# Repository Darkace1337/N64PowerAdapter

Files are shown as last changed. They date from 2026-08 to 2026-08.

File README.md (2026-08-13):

# N64PowerAdapter

A modern, universal replacement power supply for the Nintendo 64 using readily available, high-quality power modules.

This project includes the PCB design, schematic, and 3D-printable enclosure required to build a replacement for the original Nintendo 64 power supply. The supply accepts universal AC mains through an IEC C8 connector and provides the 12 V and 3.3 V rails required by the N64 through the original 6-pin power connector.

The design uses TRACO Power modules for the AC/DC and DC/DC conversion, keeping the power circuitry simple while providing an isolated and compact replacement for aging original power supplies.

## Requirements

**A sacrificial Nintendo 64 power adapter (official or third-party) is required for the original 6-pin console connector.**

The connector must be removed from the donor power supply and installed onto the replacement PCB.

## Bill of Materials

| Reference | Qty | Manufacturer | Part Number | Description |
|:---|---:|:---|:---|:---|
| PS1 | 1 | TRACO Power | TEL 10-2410WI | 10 W isolated DC/DC converter, 9–36 V input, 3.3 V / 2.7 A output |
| PS2 | 1 | TRACO Power | TMPW 25-112 | 25 W AC/DC converter, 12 V / 2.083 A output |
| C1 | 1 | KYOCERA AVX | TAJD476K025SNJ | 47 µF, 25 V, 10% tantalum capacitor |
| C2, C4 | 2 | Vishay | 05007-BR104AKU-J | 0.1 µF, 25 V, 10% MLCC |
| C5 | 1 | Vishay | 592D477X96R3C2T20H | 470 µF, 6.3 V, 10% tantalum capacitor |
| F1 | 1 | Eaton | C310T-SC-2-5-R-TR1 | 2.5 A, 250 V ceramic cartridge fuse |
| J1 | 1 | — | Amazon | C8 Panel Mount Plug, flange mount type |
| J3 | 1 | Nintendo / Donor PSU | — | Original N64 6-pin power connector |
| Screws-A | 3 | - | Amazon | M3 x 5 mm Button-head machine screws
| Screws-B | 4 | - | Amazon | M3 x 6 mm Countersunk self tapping screws
| Thread Inserts| 2 | - | Amazon | M3 x 4 mm Heat-set insets

## Project Files

* Schematic and PCB design
* Gerber/manufacturing files
* 3D-printable enclosure
* Reference photos of the assembled prototype

## Prototype / Revision Note

**The photos shown below are of an earlier prototype revision.**

The PCB used in the photographed prototype required a small section of the board to be manually cut for proper mechanical fitment. The PCB layout has since been revised to correct this interference.

The current revision is intended to fit without this modification, but has not yet been physically verified in the same configuration shown in the photos.

## Photos

<p align="center">
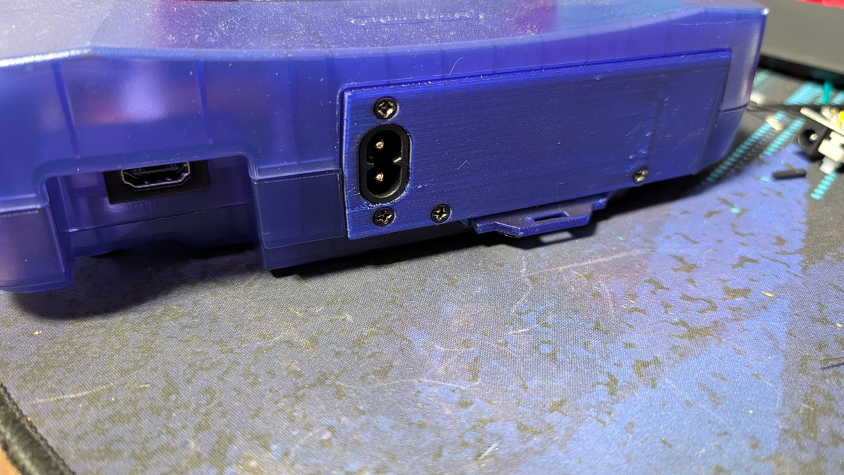
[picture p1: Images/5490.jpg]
N64 Power Adapter installed
  
</p>

<p align="center">
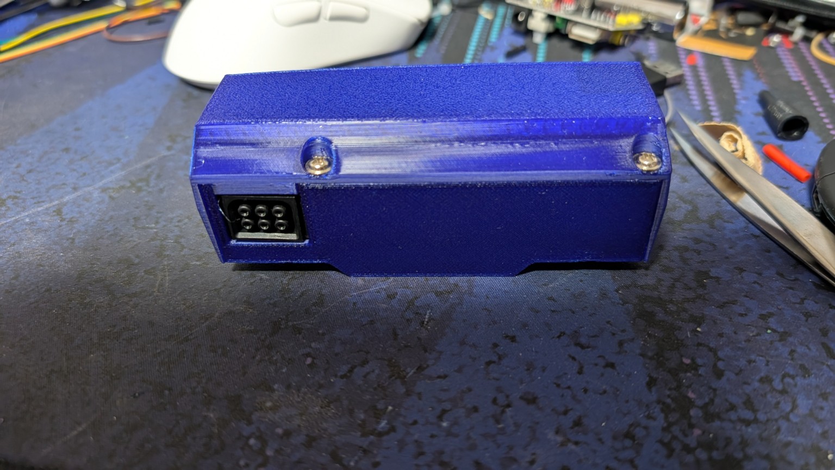
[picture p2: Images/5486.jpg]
  
</p>

<p align="center">
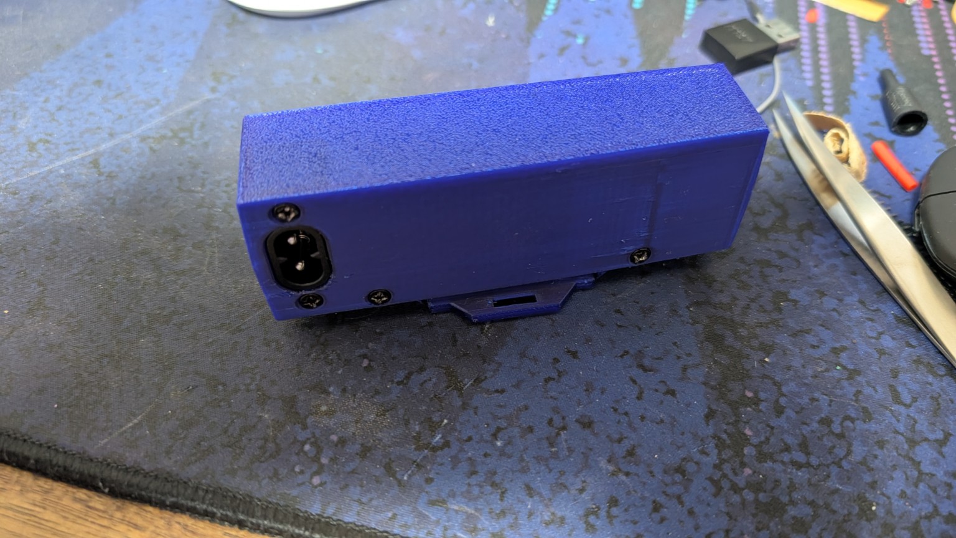
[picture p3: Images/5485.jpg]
  
</p>

<p align="center">
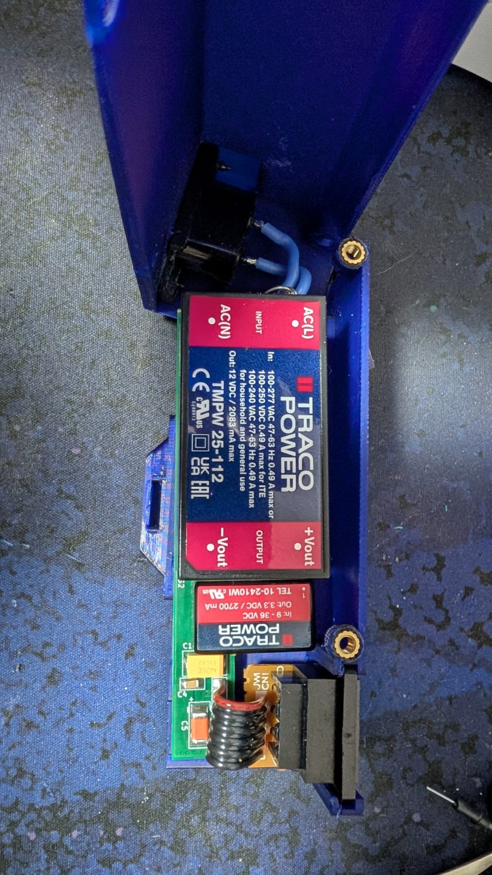
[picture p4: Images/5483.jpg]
N64 Power Adapter internal assembly
  
</p>

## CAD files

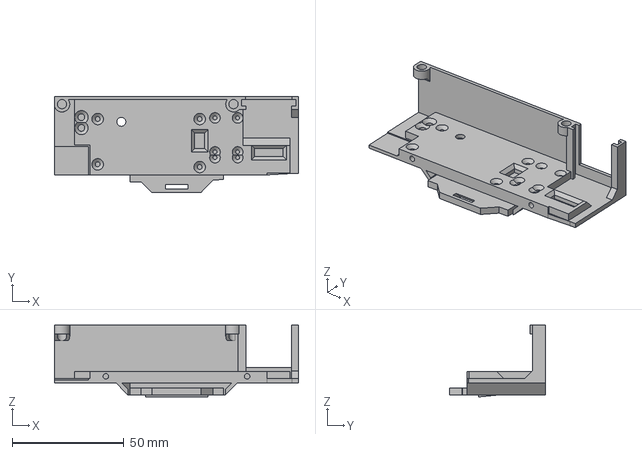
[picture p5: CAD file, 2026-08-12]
3d Print Shell/N64Power - Lower Shell.step
109.3 x 43.2 x 32.2 mm

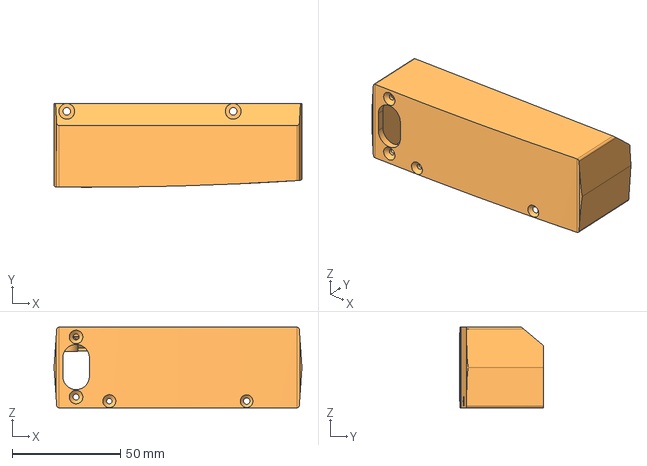
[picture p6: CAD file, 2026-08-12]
3d Print Shell/N64Power - Upper Shell.step
114.5 x 38.6 x 37.2 mm

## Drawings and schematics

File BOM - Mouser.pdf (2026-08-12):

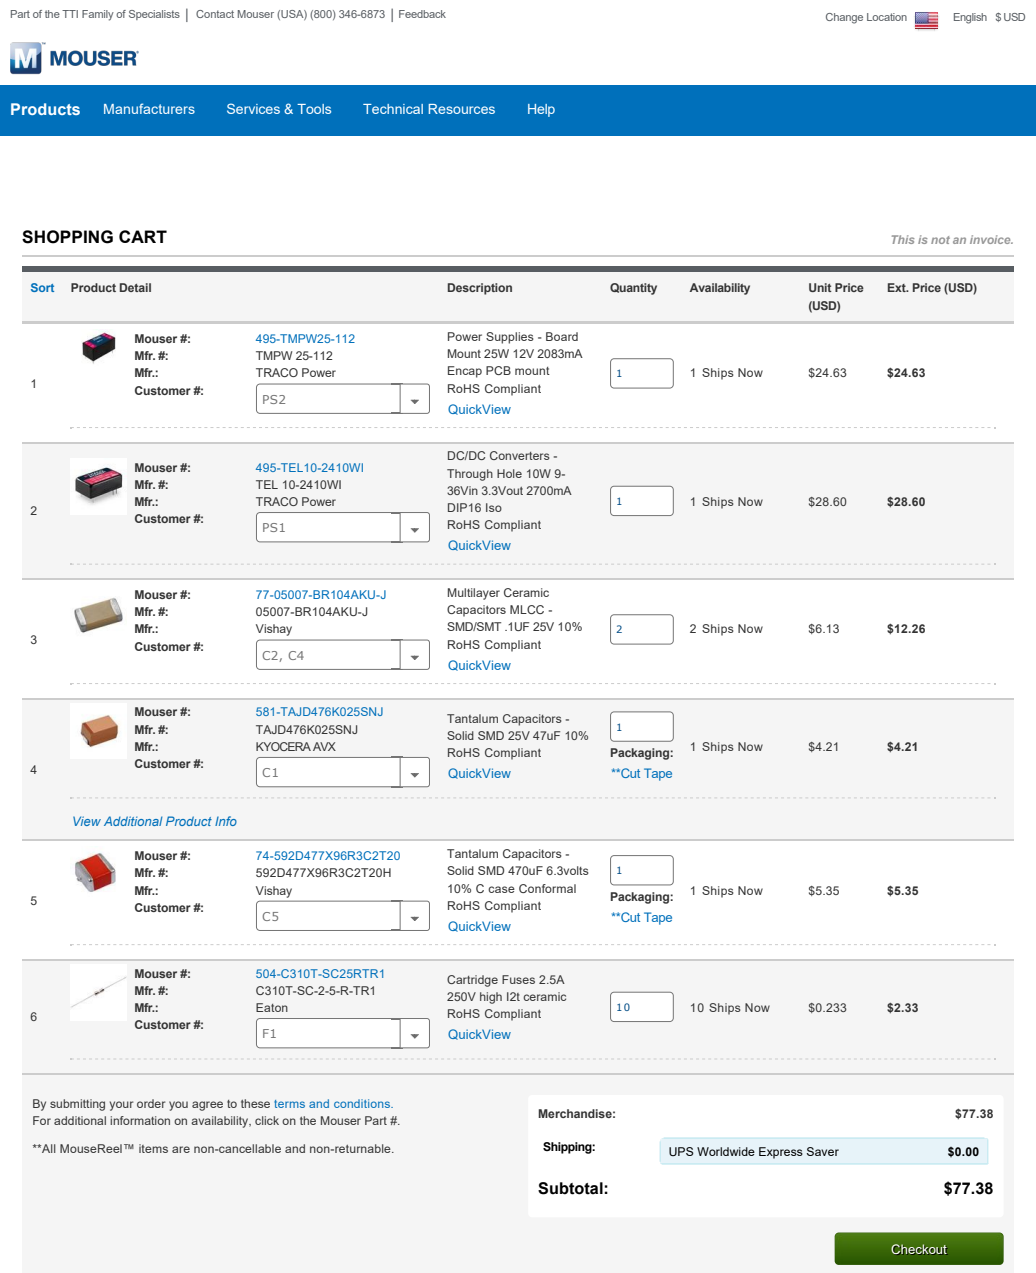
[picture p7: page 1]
Mouser #:; 495-TMPW25-112; Mfr. #:; TMPW 25-112; Mfr.:; TRACO Power; Customer #:; 1 Ships Now; 495-TEL10-2410WI; TEL 10-2410WI; 77-05007-BR104AKU-J; 05007-BR104AKU-J; Vishay; Multilayer Ceramic; Capacitors MLCC; SMD/SMT .1UF 25V 10%; RoHS Compliant; QuickView; 2 Ships Now; 581-TAJD476K025SNJ; TAJD476K025SNJ; KYOCERA AVX; Tantalum Capacitors; Solid SMD 25V 47uF 10%; Sort; Product Detail; Description; Quantity; Availability; Unit Price; (USD); SHOPPING CART; This is not an invoice.; Packaging: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

Ext. Price (USD)

Power Supplies Board
Mount 25W 12V 2083mA
Encap PCB mount
RoHS Compliant
QuickView

DC/DC Converters
Through Hole 10W 9-
36Vin 3.3Vout 2700mA
DIP16 Iso

View Additional Product Info

Mouser #: 74-592D477X96R3C2T20 (https://www.mouser.com/en/ProductDetail/Vishay/592D477X96R3C2T20H?qs=4F%2FlFts7nSw5BVSyP03OZw%3D%3D) Mfr. #: 592D477X96R3C2T20H Mfr.: Vishay | | Tantalum Capacitors Solid SMD 470uF 6.3volts 1 10% C case Conformal 1 Ships Now $5.35 $5.35 Packaging:

6 | Mouser #: 504-C310T-SC25RTR1 (https://www.mouser.com/en/ProductDetail/Eaton/C310T-SC-2-5-R-TR1?qs=1zthkiRbLn0aJh%2FodnawRA%3D%3D) Mfr. #: C310T-SC-2-5-R-TR1 Mfr.: Eaton | Cartridge Fuses 2.5A 250V high I2t ceramic RoHS Compliant QuickView | 10 | 10 Ships Now | $0.233 | $2.33

By submitting your order you agree to these terms and conditions. (https://www.mouser.com/en/saleterms)
For additional information on availability, click on the Mouser Part #.

**All MouseReel™ items are noncancellable and nonreturnable.

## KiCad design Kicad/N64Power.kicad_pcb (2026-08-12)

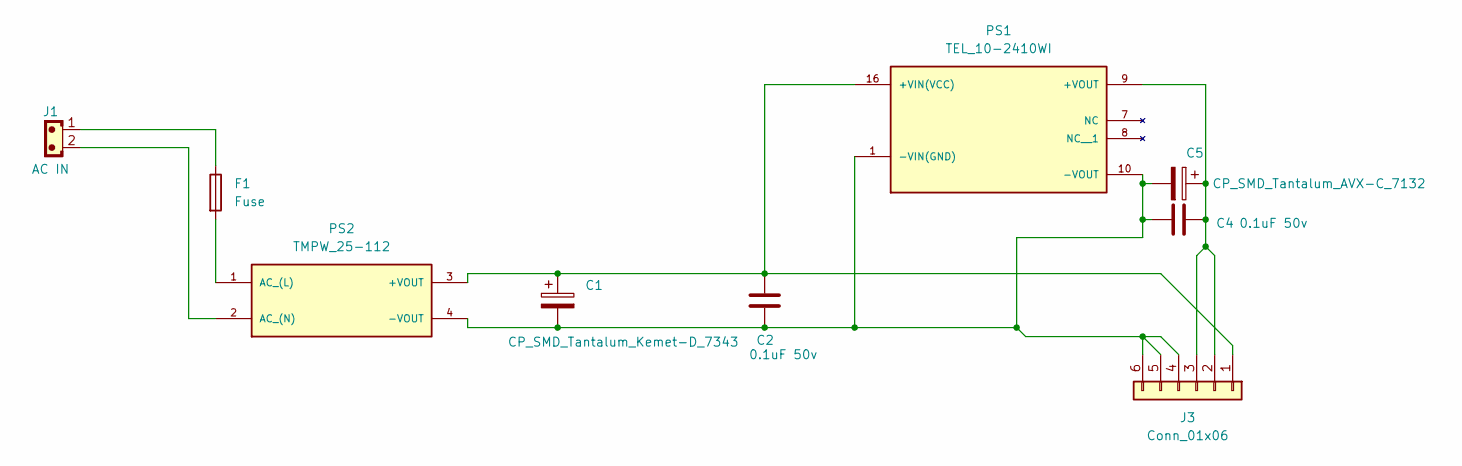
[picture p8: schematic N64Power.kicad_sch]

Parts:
C1: CP_SMD_Tantalum_Kemet-D_7343; CP_EIA-7343-31_Kemet-D
C2, C4: 0.1uF 50v; C_1206_3216Metric_Pad1.33x1.80mm_HandSolder
C5: CP_SMD_Tantalum_AVX-C_7132; CP_EIA-7132-28_AVX-C
F1: Fuse; FUSE_0683G2500-01
J1: AC IN; SolderWire-0.75sqmm_1x02_P4.8mm_D1.25mm_OD2.3mm
J3: Conn_01x06; n64ribbon
PS1: TEL_10-2410WI; CONV_TEL_10-2410WI; PARTREV June 16, 2021
PS2: TMPW_25-112; CONV_TMPW_25-112; PARTREV April 20,2021

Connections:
+3.3V: C4.2, C5.1, J3.2, J3.3, PS1.9 (+VOUT)
+12V: C1.1, C2.1, J3.1, PS1.16 (+VIN(VCC)), PS2.3 (+VOUT)
GND: C1.2, C2.2, C4.1, C5.2, J3.4, J3.5, J3.6, PS1.1 (-VIN(GND)), PS1.10 (-VOUT), PS2.4 (-VOUT)
unnamed: F1.1, J1.1
unnamed: F1.2, PS2.1 (AC_(L))
V-L: J1.2, PS2.2 (AC_(N))

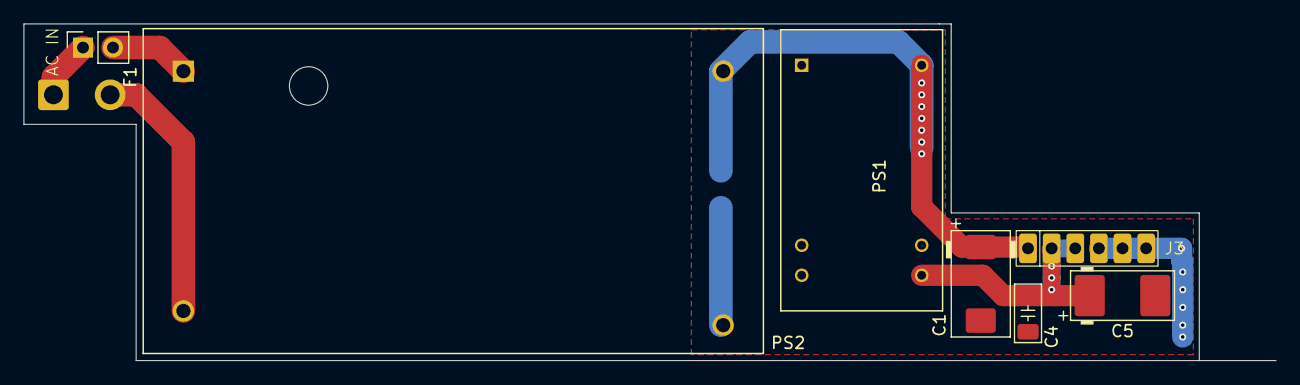
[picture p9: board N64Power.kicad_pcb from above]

Board: 2 copper layers, 106.0 x 28.5 mm, 9 parts (1 on the bottom side), 6 nets.
